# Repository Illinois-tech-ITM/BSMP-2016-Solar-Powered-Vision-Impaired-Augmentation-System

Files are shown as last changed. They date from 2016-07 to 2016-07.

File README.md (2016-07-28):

# BSMP-2016-Solar-Powered-Vision-Impaired-Augmentation-System
This repo contains code and schematics for the project to create a solar powered and battery backed vision augmentation system.

Link for the Prezi presentation: http://prezi.com/rkdpttzciynq/

**Abstract**

This project was designed to help people with tunnel vision. These people don’t have any peripheral vision and because of that they struggle with daily tasks. Our work was focused in improve a former system that addressed this issue. The system used ultrasonic sensors and vibration motors placed on a hat. Our team redesigned the prototype, changing the sensors and decided to use a backpack. The backpack was chosen because it would be more practical and would have a better performance than a hat. After changing the sensors we optimized the code to solve a couple of problems such as the serious response delay issue that the previous group had. An energy analysis was also made and a second solar panel was added to the new prototype. The electrical consumption was analyzed and optimized, allowing a full day of operation without the need of being connected to the grid. With all the optimizations and some minor design alterations, it is hoped that this project can evolve to an industrial level and, therefore, meet with the needs of any vision impaired person.

**Reconstructing the prototype:**

1) Rebuild the circuit as in the image;

2) Upload the code into the Arduino;

3) Charge the battery (approximately 3.5 hours) and plug it into the system;

4) Turn the system on and it should be working.

Circuit Image:

Circuit Image

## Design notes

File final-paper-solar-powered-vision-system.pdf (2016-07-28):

Running head: SOLAR BATPACK | 1

Solar Battery Powered Awareness of Closeness Kit - Solar BatPACK

Rafael Cejas, Marcelo Farias, Gabriela Gandorphi, Leticia Maia, Pedro Resende

IIT - Illinois Institute of Technology

Advisor: Professor Jeremy Hajek

SOLAR BATPACK | 2

Abstract

This project was designed to help people with tunnel vision. These people don’t

have any peripheral vision and because of that they struggle with daily tasks. Our

work was focused in improve a former system that addressed this issue. The system

used ultrasonic sensors and vibration motors placed on a hat. Our team redesigned

the prototype, changing the sensors and decided to use a backpack. The backpack was

chosen because it would be more practical and would have a better performance than a

hat. After changing the sensors we optimized the code to solve a couple of problems

such as the serious response delay issue that the previous group had. An energy

analysis was also made and a second solar panel was added to the new prototype. The

electrical consumption was analyzed and optimized, allowing a full day of operation

without the need of being connected to the grid. With all the optimizations and some

minor design alterations, it is hoped that this project can evolve to an industrial level

and, therefore, meet with the needs of any vision impaired person.

Keywords: Tunnel Vision, Solar Power, Arduino, Ultrasonic Sensors, Wearable.

Solar Battery Powered Awareness of Closeness Kit

Introduction

Tunnel vision is an eye disease in which a person loses his or hers peripheral vision.

Having tunnel vision is like looking through a binocular or telescope. Without their

peripheral vision, people become more susceptible bumping into things or people on

their side. That causes them to also be more susceptible to injuries from the collisions.

The idea was having a device that warns a visually impaired person when there is

something or someone nearby, and the general direction where they are.

Previous Project

Our project is the continuation of a project started by another team in a previous

semester. The previous team assembled a prototype in a hat. The hat had three sen-

sors facing the sides and the front of the person wearing the hat, and three vibration

motors in the same three sides. The motors vibrated when the corresponding sensors

recognized an object up to 70 cm (2.2 feet) from the hat. Our job was to debug and

optimize their work. The previous prototype was not left intact, so the first thing we

had to do was rebuild it in a protoboard, and run the other group’s code to see if it

works. Afterworks, we started working on the old prototype: testing, debugging and

improving.

The circuit and operation were relatively simple. Between the solar panel and the

processor (Arduino Micro) there were three components: a solar lithium ion/polymer

Charger; a 3.7V 1200 mAH lithium ion polymer battery and a PowerBoost 500 (5V

USB Boost). The solar panel was connected with the Charger, which decreased the

voltage to 3.7V (safe to the battery). Then, the PowerBoost increased the voltage

to 5V (compatible with the Arduino Micro). The three ultrasonic sensors - PING)))

model - had 3 connections each: 5V, ground and signal, and each vibration motor

(AdaFruit Mini Motor Disc) had ground and signal connections. The signals from

these devices were all connected to digital pins from the Arduino, and the 5V and

ground connections were attached to the PowerBoost correspondent pins. To deter-

mine the program status (on or off) the system had a touchpad with two connections.

One was attached in an analog pin from the Arduino (so it would be able to sense an

intense or soft touch) and the other to ground.

The Arduino, with the code uploaded in it, coordinated the operation. It was

sending the sensors’ pulse, receiving it back and evaluating the elapsed time (thus,

the distance). It also calculated a mean with the last 20 distance values (filtering)

and verified if this mean was within the 70 cm range. Finally, it vibrated the motors

accordingly with the averaged distance. Parallel to this, the code was continuously

checking the touchpad status.

A diagram from the previous circuit can be seen in Figure 1.

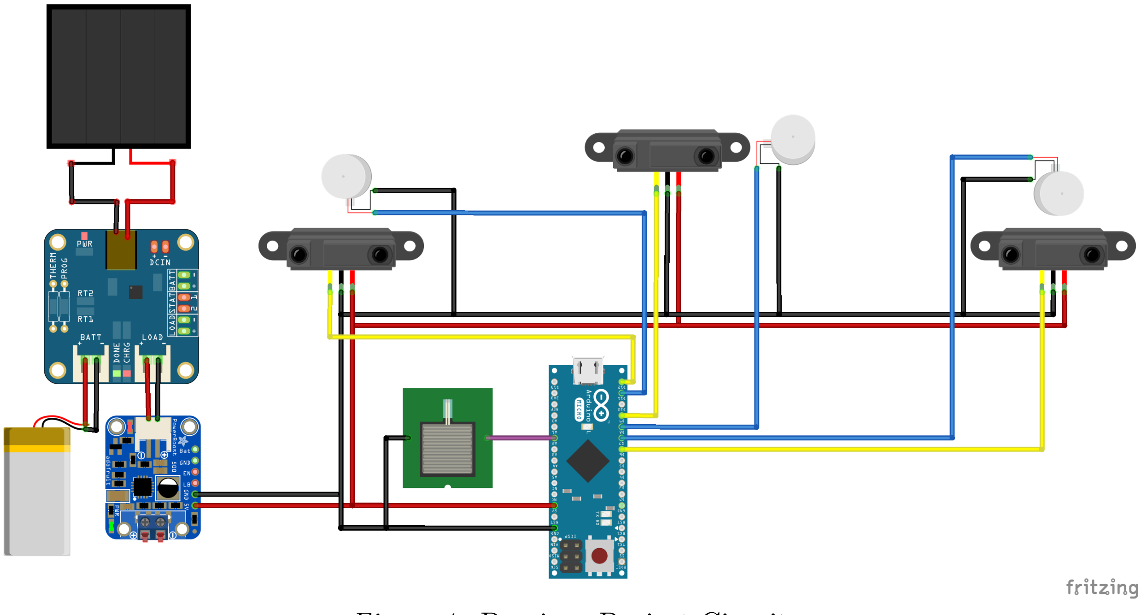
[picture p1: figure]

Figure 1 . Previous Project Circuit.

Proposed Changes and Optimizations

New Range

An alteration considered was regarding the detectable range set by the code.

The previous code had a maximum allowed distance of 70 cm, meaning that any

obstacle located further than this value would be considered too far. After observing

some everyday situations, we decided to increase the maximum allowed distance. We

sensed that 70 cm wasn’t enough to give the user time to feel the object’s presence

and deviate from it (considering an obstacle or person coming to the user’s direction).

The new maximum value set was 2 m.

Change On/Off Mechanism

One of the first things that we thought about was the on/off mechanism. The

previous group used a flexible touchpad, but they had some problems with it. They

were not able to handle well long presses to the touchpad. If a person kept pressing

the touchpad for a long time, the system would keep switching on and off. In addition,

a person could easily press the touchpad by accident just by holding the hat’s panel.

That could cause confusion, because there is no way to know if the system is on or

off without vibrating the motors. Therefore, one solution presented was to change

the flexible touchpad for a simple button.

Change of Ultrasonic Sensors

We also considered to replace the existing three PING))) ultrasonic distance sen-

sors (Figure 2a) for LV-MaxSonar-EZ1 sonar sensors (Figure 2b) that were available

in the laboratory.

There were two main reasons to consider this change. The first one was based on a primary reading of both data-sheets. It was stated that not only the LV-MaxSonar

sensors were great for people and motion detection (it can detect people up to 2.4m

distant), but also that the PING))) sensors couldn’t detect soft surfaces accurately

(such as clothes). The idea of the project wasn’t restricted to people detection only,

but since both sensors were expected to perform similarly well with solid objects, the

people detection (and, hence, cloth detection) was a key parameter to consider.

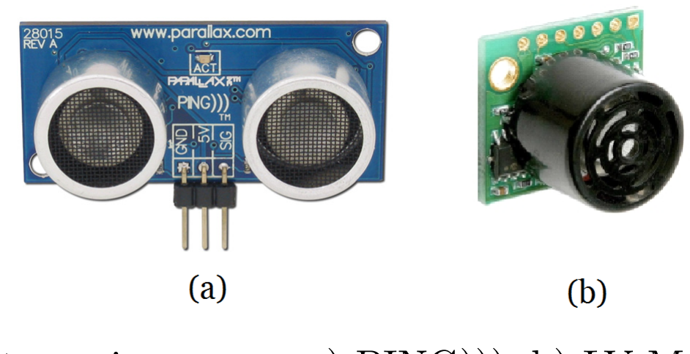
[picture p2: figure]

Figure 2 . Ultrasonic sensors: a) PING))); b) LV-MaxSonar EZ1.

The second motivation for the change was mostly aesthetic. Considering that the

system would have to be placed close to the user’s body (and visible to others), the

aspect and size of the sensors were important features. As can be seen in Figure 2,

The LV-MaxSonar-EZ1 model is much smaller and discrete than the PING))) one.

Therefore, along with the first reason mentioned, the LV-MaxSonar-EZ1 sensors were

the preferred ones for the new project.

An interesting note worth mentioning is regarding the detectable distance values

of the models. The PING))) sensors data-sheet presented a range between 2 cm and

300 cm, while the LV sensors specifications stated that they could produce distance

measurements from 15.2 cm to 645 cm. Despite the relatively large difference between

both models, the range wasn’t a main factor for the decision. Since it was determined

that a detection up to 2 m was satisfactory, both sensor models were adequate for

the purpose.

Several tests were performed to confirm all those specifications, and the results

are presented later in this report.

Code Optimization

One of the problems that were presented to us at the beginning, was a delay in

vibration, that could be related to a slow code. One thing we noticed that could be

optimized was the loop to calculate the mean of the distance values every time a new

value was added. The new mean could be simply calculated by subtracting a value

and adding another.

Regarding the optimization of energy consumption, we thought of implementing a

sleep function. We would put the processor to sleep while the system was off, reducing

the number of used processor cycles, and, therefore, reducing the energy use.

Change in Vibe Motors’ Output Mode

The previous group had devised a way to relate the proximity of an object to

a certain kind of vibration interval. As an object got closer, the interval between

vibrations would decrease, and that way the person would have an idea of their

distance to the object. We discovered that the sensors could be used with analog

output (0-255 instead of HIGH/LOW) and thought that it might make the program

simpler if we, instead of relating distance to pause between vibrations, related it to

intensity of vibration. That way, as an object got closer, a person would feel a stronger

vibration.

Move System to a Backpack

The prototype in a hat made sense because it was easy to put on and remove, but

we found some problems with it, such as:

- Carrying all the weight of the system on the head;
- Feeling the vibration on the head might be uncomfortable;

- The height that the sensors were placed made it harder to identify some obsta-

cles.

At first, It was suggested that we rebuild the prototype in a shirt, because that

would help with the issues listed above. However, other problems came up. The shirt

would not be washable, and It would not be easily removable.

Improving the idea, we thought about a backpack, with a pocket to hold the

system, the solar panel spread in the back, one sensor and vibration motor in each

strap, and one sensor and vibration motor in the back. After we built a rough

prototype, we thought It would be better to add a strap around the waist to keep the

backpack in place. We also moved one vibration motor from the back to this strap,

because It was easier to feel the vibration there.

Add Second Solar Panel

Given the previous prototype, our main idea was to perform a complete energy

analysis in order to fully understand the energy dynamics of the system. However,

even before running any tests, we had some ideas that included the possibility of

adding a second solar panel to the project. Since we decided to move the system from

the cap to the backpack, the additional space would make it possible to add a new

panel and therefore increase our power production.

Preliminary Tests and Results

Previous Prototype

After thinking and brainstorming new ideas and possible changes to the project,

we started the actual tests in order to further analyze the energy consumption and

production of the previous prototype. First, we decided to test all components separately, starting with a voltage test on the solar panel. The next step was to check

the other components by creating an appropriated circuit for each one of them.

Once we knew that all the components were working properly, we moved on to

the energy consumption analysis. The analysis consisted on using the multimeter

to measure the current at different places (current leaving solar panel, current arriv-

ing/leaving battery, and current leaving PowerBoost/arriving system) and situations

(sunny day and cloudy day). All the tests were made on IIT campus, during the

summer, and from 10AM to 3PM, so we could have a good range of solar insolation.

The values measured are located on Tables 1 and 2 and each situation is shown.

During our tests, we realized that the system would consume a significant amount

of energy even when it was turned off. In the case of having the battery as the only

source of energy, the current leaving the PowerBoost with the system turned off was

about 55mA (Table 1).

Table 1
Current measurements in different part of the system, for different situations

Without Solar Panel

Current Leaving | Current in each | Current in each
PowerBoost | Ultrasonic Sensor | Vibration Motor
[mA] | [mA] | [mA]

Situations

Only
Battery

From
Computer

Only
Battery

From
Computer

Only
Battery

From
Computer
Button Off | 55.0 | 42.0 | 6.2 | 5.9 | 0.00 | 0.00
Button On, Without Obstacles | 69.0 | 57.0 | 12.0 | 12.0 | 0.02 | 0.05
Button On, Closest Obstacles | 170.0 | 121.0 | 8.0 | 7.9 | 45.0 to
| | | | | 49.0 | 45.0 to
| | | | | | 49.0

Besides that, we estimated the consumption of the battery, measuring the current

leaving it in different scenarios, these different situations helped us to estimate the

energy necessary for a normal day of use (Table 2).

After calculating the energy consumption and the usage of the battery, we decided

to analyze how one solar panel would affect the situation. To evaluate that, we ran

the battery tests again, first using a reliable source of electricity (a laptop via USB)

and then using a solar panel during different insolations. As we expected, the laptop

provided a constant current to the battery while generating energy for the system in

different situations as it can be seen also in Table 2.

Table 2
Current measurements into the battery, for different situations

Current Into the Battery; System Attached

Without Solar
Panel; Nor
Computer [mA]

Without Solar
Panel; With
Computer [mA]

With One
Solar Panel [mA]
Situations | | | Sunny Day | Cloudy Day
Button Off | -90 | 43.9 | 55 | -72 to -85
Button On, Without Obstacles | -92 | 44.1 | 32 | -119
Button On, Closest Obstacles | -350 | 44.3 | -195 | -400

On the other hand, the solar panel proved to be much more inefficient. We already

knew before starting that our flexible solar panel would generate less than 167 mA

at its best, due to its specifications. During our experiments, we concluded that the

solar panel would charge the battery only in two situations, both in a sunny day:

when the system was off or when it was on but with no obstacles in its surroundings.

In all other situations the solar panel wouldn’t provide enough energy to the system, and consequently would only slow down the battery’s discharge. The numbers were

really relevant and we discovered that during a cloudy day, the system would drain

the battery even if the button was off.

Battery Tests

After acquiring these data we decided to run a different test. We tried to confirm

how long would take to fully discharge our batteries. First we used the battery

specifications, the measured current and voltage to calculate how long it should take

to drain the battery. Doing that, we estimated that it would take around 5 hours

to discharge the battery while the system was detecting an obstacle at the closest

range. We also calculated that It would take around 12 hours to discharge it while

the system was on but not detecting anything, and around 13 hours with the button

turned off.

To confirm our calculations we ran the following test. First, we fully charged our

battery to be sure we had it maximum charge. Then, we connected it to the system

in the three different situations described. Our empirical results were: 4.5 hours to

drain the battery when an obstacle was placed right in front of the sensors, around 10

hours with the button on without obstacle and around the same for when the system

was off.

Second Solar Panel

Following the decision of adding the second solar panel, we started running tests

again, now with two solar panels attached to the system. This decision was made

in order to increase the energy production, and therefore improving our battery life

and the system’s efficiency as a whole. Our tests consisted on measuring the current

leaving the set of two solar panels and the current arriving/leaving the battery at the same conditions as the previous tests. As we can see in Table 3, the results were in

general as good as expected and in some cases, even better than so. The only curious

result was the current going to the battery on a sunny day with obstacle close to the

sensors. With one panel the current was leaving the battery with 195 mA, but with

2 panels the battery was being charged with 65 mA. This represents an increase of

133%.

Table 3
Current into the battery, with two flexible solar panels, for different situations

Current Going to the Battery, With Two Flexible Solar Panels (System attached) [mA]

Situations | Sunny Day | Cloudy Day
Button Off | 155 | -57
Button On, Without Obstacles | 153 | -70 to -76
Button On, Closest Obstacles | 65 | -350 to -370

Hard Solar Panel

Another solution for this problem was to change the solar panel, since there are

several types of solar panels and technologies that can provide enough energy for our

system. One example was the Medium 6V 2W solar panel from Adafruit, which was

used in one of our prototypes. This panel had a higher output than the two flexible

ones combined. However, after some tests, we decided to stick with the two flexible

panels because of the effect of shading in both solutions. If a shadow was placed

on only 1/6 of the new solar panel, its output current would drop from 150 mA to

20 mA. On the other hand, to make the flexible solar panels drop to 20 mA it was

necessary to place a shadow upon 1/2 of their area. Since we expect that the users

will face several shadows upon the solar panels, we decided to use the solar panels that had a better response to shading, the two flexible ones.

Sleep Function and Optimization in Energy Consumption

The sleep function is triggered when the Arduino starts or when the button is

pressed. This function allows the Aduino to stay on without running the code, at a

low energy cost. When the button is pressed, the vibration motors and the sensors

are turned off and the Arduino sleep function is executed. We set the button pin as

an interrupt pin that wakes up the Arduino when the button is pressed. After waking

up, the Arduino runs the end of the sleep function, which will enable the vibration

motors and sensors again. This optimization resulted in a big improvement in terms

of energy use. The current from the PowerBoost to the system before the addition

of the sleep function, when the button was off, was 55 mA. After we added the code

to put the system to sleep, it became 26 mA. This is about a 45% improve in energy

use.

In the search for a greater reduction, we used a transistor to block the current to

the sensors while the Arduino slept. This helped saving even more energy, because

only the Arduino remained on while the system was off, using only 7 mA.

Despite these great results, by replacing the button for a switch between the

Charger and the PowerBoost, we reduced the amount of energy required by the

system to negligible values. Measuring the current leaving the battery we found 28.3

µA, probably due to the Charger circuit. With this value, besides the amount of

energy saved, the battery can even be charged with low insolation.

Ultrasonic Sensors

Before implementing the LV-MaxSonar-EZ1 sensors into the system, some tests

were performed to support the decision, and also to validate the information given in

both data-sheets.

Single Sensor Tests. For the first tests, we used a simple code that was just

sending the pulse and evaluating the distance. With this code and only one sensor of

each model, some interesting results were noticed.

For both models, the sensors detectable distance range showed to be accordingly

with the specifications stated in the data-sheets, as presented in Table 4.

Table 4
Detectable Distance Range for both Models

Sensor’s Model

PING))) | LV-MaxSonar EZ1
| Laboratory Test | Data-Sheet | Laboratory Test | Data-Sheet
Minimum Distance | 3 cm | 2 cm | 20 cm | 15.2 cm
Maximum Distance | 311 cm | 300 cm | 635 cm | 645 cm

The PING))) sensor presented inaccurate measures when trying to detect clothes.

For short periods of time, with a person standing just in front of the sensor and with-

out moving, the sensor outputted its maximum detectable distance value (311 cm).

A probable explanation is that the emitted pulse was being absorbed by the clothes

and thus, since it wasn’t returning or taking much longer to do it, the program was

interpreting that the object was at the furthest location possible. The LV-MaxSonar

presented excellent results with clothes, with just rare cases of imprecise values.

We also observed that the LV-MaxSonar-EZ1 model was very sensible to its con-

nections. An intense handling of the cables caused the distance measured values to

sometimes reach zero. Furthermore, when this situation occurred, the program’s loop

time increased significantly.

Both sensors showed extremely fast responses in this simple situation, without

significant delay of any kind.

Complete System Tests. After these observations, for each model, the system

was assembled with the three sensors needed, and the previous project’s working code

was uploaded for more tests.

Regarding the detection of soft objects, such as clothes, the system with the LV

sensors provided accurate distance values. On the other hand, when PING))) sensors

were used, the measurements were, as expected, very imprecise, causing the vibe

motors to wrongly vibrate or, sometimes, not vibrate at all.

With the three LV sensors, the same sensibility problem regarding connections

was identified. At first, it was confused with an interference issue, since three sensors

were in use, and the zero distance values were happening much more often. However,

after several trials and tests the cables influence became clear when by only handling

the sensors’ connections, the accurate values reappeared.

With the three PING))) sensors, the system didn’t present any significant response

delay. On the other hand a relatively long response delay was noticed with the LV-

MaxSonar-EZ1 model. The time taken for a vibe motor to vibrate after placing an

object in front of the correspondent sensor was slightly less than two seconds (still

relatively high).

After several code reviews and tests, we identified the problem. To reduce noise,

the code was performing an average of the last 20 values of distance and using this

averaged value to dictate whether the motor should vibrate or not. After placing

an obstacle in front of the sensors, a new distance value was being added to the

old 19 values, producing a new mean. However, when the older 19 values were

somewhat different from this new distance the new mean was not so distant to the

old mean. Therefore, the delay was happening because it was taking a longer time for the averaged value to get closer to the real distance.

The solution was simply to ignore the average, and leave the instantaneous dis-

tance values from the sensors dictate the vibration. The result was very satisfactory

and the LV-MaxSonar sensors didn’t present a severe problem regarding noise. The

moments where the motors vibrated without obstacles near were rare.

Decision and Important Note. As presented above, several factors contributed

to the final decision of using the LV-MaxSonar model in the final prototype. The most

relevant one was definitely the accuracy when identifying people. It wasn’t practica-

ble to use the PING))) sensor in the project. The main idea of this concept was to

detect obstacles so that the user don’t collide with them while walking. Therefore,

using a sensor that for several periods of time simply miss soft objects wasn’t a feasi-

ble possibility. The LV-MaxSonar model presented excellent results with clothes and,

with the delay problem solved, was a solid choice for the new prototype.

Note. All the tests described between subsections "Previous Prototype" through

"Sleep Function and Optimization in Energy Consumption" were performed with the

PING))) sensors attached to the system. To also be able to justify the same con-

clusions and decisions that arose from those tests for the LV-MaxSonar EZ1 model,

some other measurements were performed to ensure the power-consumption similarity

between sensors.

Table 5 presents the measured current leaving the PowerBoost for the exactly same

situations as the PING))) sensor was submitted, when only the battery was providing

the energy. The values from the PING))) sensor were added for comparison.

The values show that, not only the proposed new sensor is similar to the previous

one, validating all the former conclusions, but also it requires less energy from the

battery.

Table 5
Current leaving PowerBoost. Both sensors comparison (Only Battery)

Current Leaving PowerBoost

| LV-MaxSonar EZ1 | PING)))
Button Off (Sleep On) | 7 mA | 7 mA
Button On, No Obstacles | 40 mA | 69 mA
Button On, Closest Obstacle in all three | 160 mA | 170 mA

Vibration Motors’ Output Mode

We changed the code to support different vibration intensities, and then tested

the prototype with these changes. However, the difference between two vibration

intensities was barely noticeable. Therefore, we thought that the intensity output

could not serve the purpose of indicating distance. We discarded the changes and

went back to telling distance from the length of the interval between vibrations.

Solar BatPACK

Solar BatPACK stands for Solar Battery Powered Awareness of Closeness Kit.

Considering all the tests and discussions mentioned on the sections above, we set the

new configuration for this new prototype.

Components and Circuit

The circuit was assembled as Figure 3 shows. The list of components used in

this project can be seen in Table 6. The table also refers to each component as the

correspondent letter presented in Figure 3.

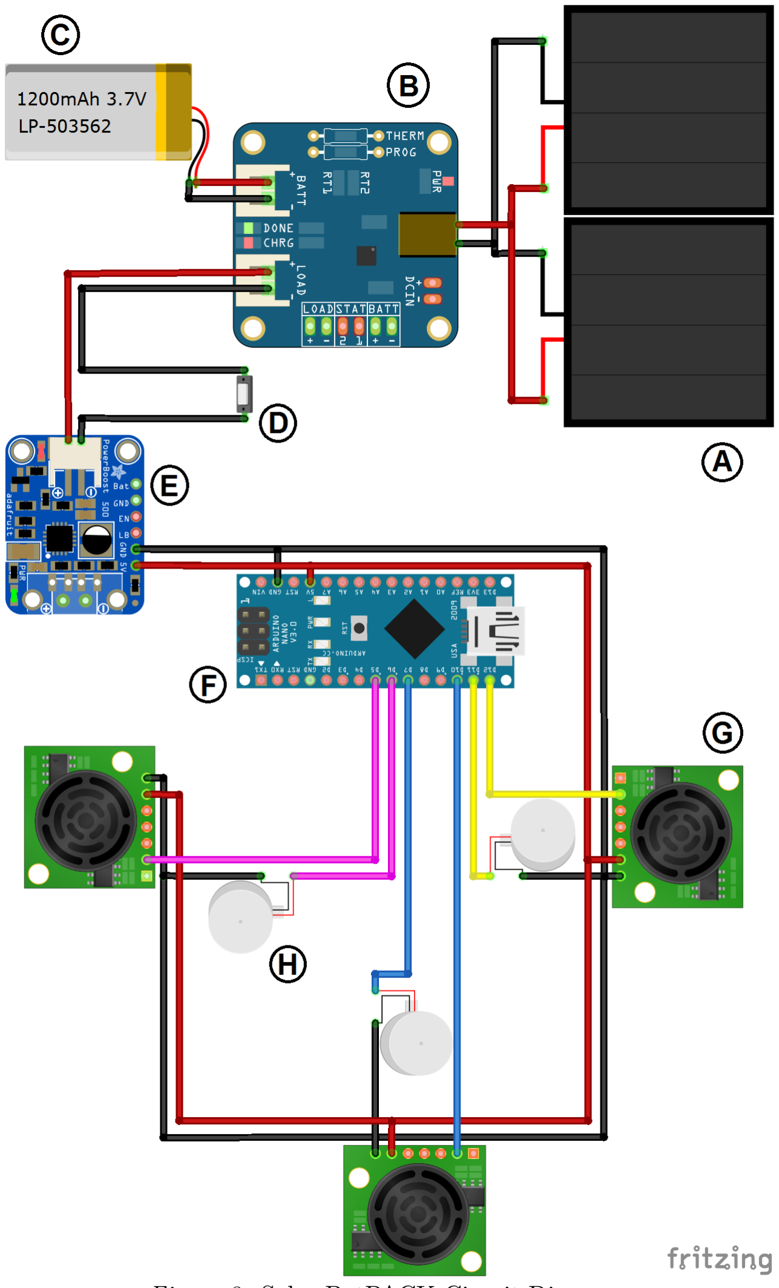
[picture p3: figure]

Figure 3 . Solar BatPACK Circuit Diagram.

Table 6
List of Components used in the new Prototype. Letters refering to Figure 3

Letter
Reference | Quantity | Type | Model Name
A | 2x | Flexible Solar Panels | AdaFruit 6V 1W
B | 1x | Charger | USB/DC/Solar Lipo Charger
C | 1x | Lipo Battery | LP-503562, 3.7V 1200mAh
D | 1x | Slide Switch | Breadboard-Friendly SPDT
E | 1x | PowerBoost | 500 Basic - 5V USB Boost
F | 1x | Arduino | Micro
G | 3x | Ultrasonic Sensor | LV-MaxSonar-EZ1
H | 3x | Vibrating Motors | AdaFruit’s Mini Motor Disc

Without any sun, or inside closed spaces, the battery provides all the power to the

Charger. When the switch is off, no energy can go to the PowerBoost and there is a

negligible amount of energy being wasted (28.3 µA leaving the battery, as mentioned).

With the switch on, the current flows to the PowerBoost which provides the correct

voltage to the system (5V).

The PowerBoost’s 5V pin is connected with the Arduino’s and with the three

sensors’ 5V input, while its ground pin is connected with the Arduino’s, the three

sensors’, and the three motors’ ground input.

The sensors’ third connection was made between their PW pin and the digital

pins from the Arduino. The distance could be calculated using the scale factor of 147

µs per inch provided in the data-sheet.

The three motors’ second connection was made between their red wire and the

digital pins from the Arduino. When these digital pins were set to HIGH in the

Arduino, the current went to the motors, causing them to vibrate.

With some insolation, the only difference in the system is that, with the switch

on, the energy produced in the solar panels can help the system by decreasing the

energy required from the battery. If the insolation is high enough, it can even charge

the battery while on (as presented in the previous tests). With the switch off, any

amount of energy produced by the panels charges the battery.

Code

One modification we made in the code was the change in vibration levels. The

other group used seven different vibration levels to represent distance. We noticed

that the difference between two vibration levels was not very noticeable, so we changed

that to four different frequencies. The frequency level for a distance can be calculated

by dividing the distance value by 50, since the range is 200 cm.

There are two built-in functions in the Arduino code, setup() and loop(). In the

setup(), we define the pins and initialize a timer object. The loop() function is the

body of the program. We have a variable i that changes between the three sensors

every iteration. In the loop function, first, we call the pingDistance(i) function, with

the current i as a parameter. The pingDistance() function will update the value

read by sensor i, and update the distance level for that sensor, which is distance/50.

Afterwards, we call timer.run(). The method timer.run() will call vibrateAll() every

60 ms. The method vibrateAll() will iterate through the three motors and call vibrate()

for each of them. In vibrate(), we check if the current distance of the object is inside

the spectrum of vibration (< 200 cm). If that is true, we vibrate according to the

distance level, which means that we vibrate once and don’t vibrate distance level - 1

times. If the distance is greater than 200 cm, we do not vibrate the motor.

The figure below presents the code’s diagram.

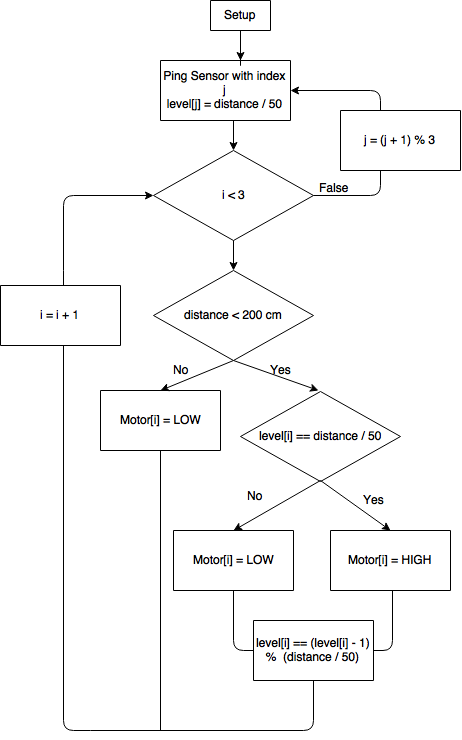
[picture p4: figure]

Figure 4 . Code’s Diagram.

Conclusion

After all this effort we could conclude that there are several aspects that may affect

the performance of the system. First it was needed to select the right sensors, since

that each sensor has some advantages and disadvantages. The connections are also

an important issue that must be addressed when building this kind of prototype. Bad

connections may create noise and compromise the system. After a lot of work, the

code is optimized when compared with the previous prototype and different problems

were solved. After the changes on the solar panel and on how the system turns off,

it is safe to say that the prototype can be used during a whole day without the need

to be connected to the grid. Other aspects were chosen thinking about the user and

the best way to implement this kind of system. That is why we decided to use a

backpack and change the number of vibration levels.

In addition to that there are other problems that were considered but due to the

lack of time weren’t fully addressed. However, the group already thought of some

solutions. This includes a pair of bracelets with extra vibrations motors that would

be used during cold days when the clothes may interfere on the user’s sensitivity.

Also we thought about crafting a protection case necessary for some parts of the

system. With all that been said, the BatPack works on different situations, has a

great response time and is already fully functional. Some minor aspects need to be

addressed, such as a more exquisite design.

References

Chio, Y; Kim, Y; Oh, C; Okhandiar, N. & Illinois Institute of Technology. (2015).

Clothing Based Proximity Sensors for the Visually Impaired. Retrieved from:

https://github.com/jhajek/ITMT492-SPRING2015/tree/master/Clothing-

Based-Proximity-Sensors-for-the-Visually-Impaired/Final_Embeded

Dubilier Industries. Specification of Li-polymer Rechargeable Battery. Retrieved from:

http://datasheet.octopart.com/LP-503562-IS-3-BAK-Industries-datasheet-

12495847.pdf

MaxBotix INC. LV-MaxSonar-EZ Series High Performance Sonar Range Finder.

Retrieved from: http://maxbotix.com/documents/LV-MaxSonar-EZ_

Datasheet.pdf

Parallax INC. PING))) Ultrasonic Distance Sensor Data-Sheet. Retrieved from:

https://www.parallax.com/sites/default/files/downloads/28015-PING-

Sensor-Product-Guide-v2.0.pdf

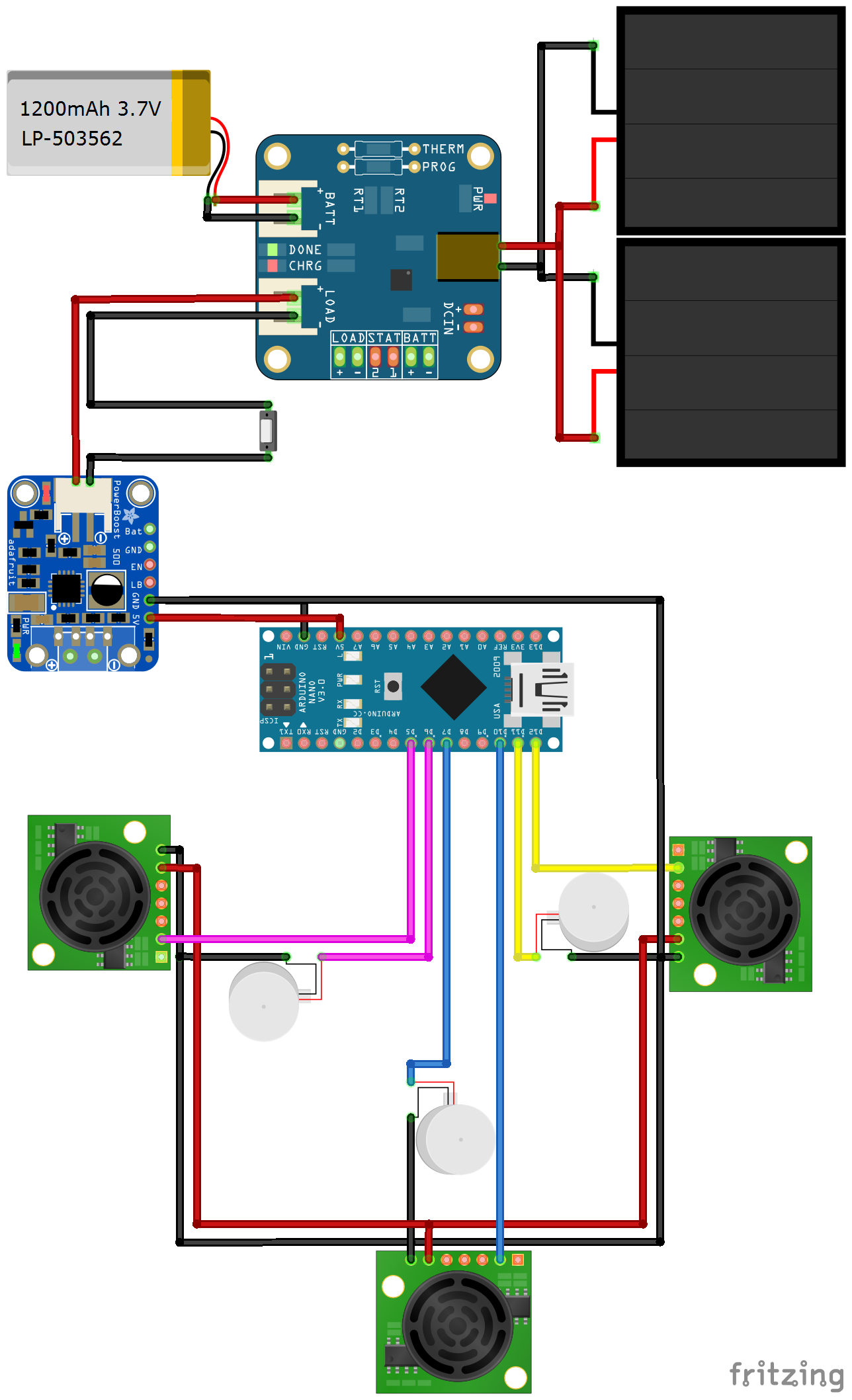
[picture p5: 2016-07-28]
Presentation/Circuit.png

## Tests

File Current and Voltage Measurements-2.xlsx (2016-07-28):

Admeasurement of Current and Voltage, in different parts of the system and in different situations
Situations | Current Leaving Power Boost (Without Solar Panel) |  |  | Current in each Ultrasonic Sensor (Without Solar Panel) |  |  |  |  | Current in each Vibrating Motor (Without Solar Panel)
 | Only Battery | From Computer |  | Only Battery |  |  | From Computer |  | Only Battery |  | From Computer
Button Off | 55-26-7 mA | 42 mA |  | 6.2 mA |  |  | 5.9 mA |  | 0 mA |  | 0 mA
Button On, Without Obstacles | 69 mA | 57 mA |  | 12 mA |  |  | 12 mA |  | 0.02 mA |  | 0.05 mA
Button On, Closest Obstacle | 170 mA | 121 mA |  | 8 mA |  |  | 7.9 mA |  | 45 to 49 mA |  | 45 to 49 mA
Button On, Furthest Obstacle | 66 mA | 60 mA |  | - |  |  | - |  | - |  | -
Button On, Obstacle at Middle Distance | 95 mA | 91 mA |  | - |  |  | - |  | - |  | -
catiorro | Voltage Leaving Power Boost (Without Solar Panel) |  |  | Voltage in Ultrasonic Sensors (Without Solar Panel) |  |  |  |  | Voltage in Vibrating Motors (Without Solar Panel)
 | 5 V |  |  | 5 V |  |  |  |  | 2.6 - 2.7 V
Situations | Current Going to the Battery (Without Solar Panel nor Computer; System attached) | Current Going to the Battery (Without Solar Panel; With Computer; System attached) |  | Current Going to the Battery (With ONE Solar Panel only; System attached) |  |  |  |  | Current Going to the Battery (With TWO Solar Panel only; System attached)
 |  |  |  | Sunny Day |  | Cloudy Day |  | Shadow | Sunny Day | Cloudy Day |  | Shadow
Button Off | -90 mA | 43.9 mA |  | Old: 85 mA |  | Old: -68 to -73 mA |  | Old: -96 mA | 155 mA | -57 mA |  | -86 mA
 |  |  |  | New: 55 mA |  | New: -72 to -85 mA
Button On, Without Obstacles | -92 mA | 44.1 mA |  | Old: 62 mA |  | Old: -107 mA |  | - | 153 mA | -70 to -76 mA |  | - 120 mA
 |  |  |  | New: 32 mA |  | New: -119 mA
Button On, Closest Obstacle | -350 mA | 44.3 mA |  | Old -150 mA |  | Old: -380 to -390 mA |  | Old: more than -200 mA | 65 mA | -350 to -370 mA |  | -330 mA
 |  |  |  | New: -195 mA |  | New: ~ -400 mA
Situations | Current Leaving Solar Panel System (ONE Solar Panel) |  |  | Current Leaving Solar Panel System (TWO Solar Panel) |  |  |  |  |  |  |  | Note:
 | Sunny Day | Cloudy Day |  | Sunny Day |  |  | Cloudy Day |  | Shadow |  |  | Under 100 mA leaving solar panel, not enough to power the system
With Battery; System Attached (All three main situations) | Old: 156 | Old: 26 mA |  | 273 mA |  |  | 36 mA |  | 4 mA
 | New: 128 | New: 20 to 23 mA
No Battery; System Attached; Button Off | Old: 89 mA | Old: 17 mA |  | 94 mA |  |  | 36 mA
 | New: 127 mA | New: 21 mA
No Battery; System Attached; Button On, Closest Obstacle | Old: 157 mA | not enough to turn the system on |  | 215 mA |  |  | not enough to turn the system on
 | New: not able to measure | not enough to turn the system on
No Battery; System Attached; Button On,Without Obstacle | Old: 157 mA | not enough to turn the system on |  | 104 mA |  |  | not enough to turn the system on
 | New: 126 mA | not enough to turn the system on
Charging | Current Going to the Battery (With Computer; NO System Attached) | Current Going to the Battery (With ONE Solar Panel; NO System Attached) |  |  | Current Going to the Battery (With TWO Solar Panels; NO System Attached) |  |  |  | Note:
 |  | Sunny Day | Cloudy Day |  | Sunny Day |  | Cloudy Day |  | Maybe it reached the limit that the charger can provide to the battery. Research datasheet.
 | 27.8 mA | Old: 154 mA | Old: 12 to 14 mA |  | 148 mA |  | 27 to 31 mA
 |  | New: 130 mA | New: 9 to 12 mA

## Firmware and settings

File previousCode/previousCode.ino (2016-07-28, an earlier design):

#include <SimpleTimer.h>
/*This code was forked from github repo
  https://github.com/jhajek/ITMT492-SPRING2015/blob/master/Clothing-Based-Proximity-Sensors-for-the-Visually-Impaired/Final_Embeded/programCode.txt */

#define SIGNIFICANT_DISTANCE 50 // The distance value between vibration levels
#define maxDistance 200 // The maximum distance to consider obstacles
SimpleTimer timer; // Timer to synchronize the frequency of the vibration motors
int sensorsPin[3] = {5, 10, 12}; // Pins for each sensor
int vibrationMotorPins[3] = {6, 7, 11}; // Pins for vibration motors
int distance[3]; // Distances from each sensor
int distanceLevel[3]; // Array of frequencies for each side
int pause[3]; // Variable used to synchronize the frequency of the vibration motors
int pointer; // Variable to iterate sensors between loops

void setup() {
  // Declare the vibration motors as output pins
  for (int i = 0; i < 3; i++)
    pinMode(vibrationMotorPins[i], OUTPUT);
  timer.setInterval(60, vibrateAll); // Set the period of vibrations
}

void loop() {
  pingDistance(pointer++ % 3); // Check the distance of a sensor
  timer.run(); // Vibrate all motors
}

// This function checks all frequencies and vibrates according to the frequency values
void vibrateAll() {
  for (int i = 0; i < 3; i++)
    vibrate(i); // Vibrate each of the three motors
}

// Vibrate if object is inside the maximum distance, acording to the frequency
// Vibrates once and pauses for ((maxDistance / SIGNIFICANT_DISTANCE) - 1) periods, then restarts
void vibrate(int side) {
  if (!tooFar(side)) { // Verify if it is inside the maximum distance
    if (pause[side] == distanceLevel[side]) { // Vibrates once
      digitalWrite(vibrationMotorPins[side], HIGH);
      pause[side]--;
    } else if (pause[side] < distanceLevel[side]) { // Pauses the vibration for the other periods
      digitalWrite(vibrationMotorPins[side], LOW);
      pause[side]--;
    }
    if (pause[side] <= -1 || pause[side] >= distanceLevel[side]) { // Restarts the pause counter
      pause[side] = distanceLevel[side];
    }
  } else { // Power off the motor if there is no obstacle in the maximum distance range
    digitalWrite(vibrationMotorPins[side], LOW);
  }
}


// If change in distance is significant, then set frequency (distanceLevel)
// Trigger each sensor, checks if it is inside the maximum distance range, and define the distanceLevel
void pingDistance(int side) {
  distance[side] =  getDistance(sensorsPin[side]);
  if (!tooFar(side)) {
    distanceLevel[side] = distance[side] / SIGNIFICANT_DISTANCE;
  }
}

// Sends a pulse to the sensor and return the distance in centimeters based on the response time from the sensor
long getDistance(int pingPin) {
  pinMode(pingPin, INPUT);
  long duration = pulseIn(pingPin, HIGH);
  long cm = duration * 2.54 / 147;
  return cm;
}

// Check if ditance to object is irrelevant
bool tooFar(int side) {
  if (distance[side] <= maxDistance && distance[side] > 0) {
    return false;
  }
  return true;
}

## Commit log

2016-06-15 Adapting code to support new sensors
2016-06-21 Swiching back to old sensors, optmizing code and changing motors to vibrate with intensity related to the distance from an object.
    [previousCode.ino]
2016-07-18 modfying code for button
2016-07-28 commiting the final files
    [Circuit.fzz, Current and Voltage Measurements-2.xlsx]
2016-07-28 Circuit Image
2016-07-28 Add circuit image
